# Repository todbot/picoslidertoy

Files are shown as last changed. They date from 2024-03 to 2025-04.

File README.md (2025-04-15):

# picoslidertoy
  
<a href="https://www.tindie.com/products/todbot/picoslidertoy-capsense-controller-for-pico/">
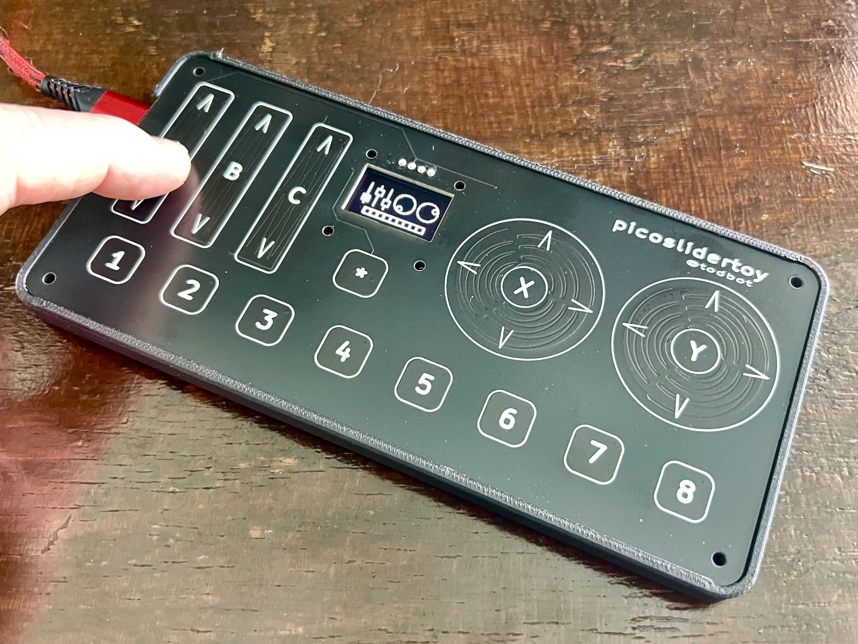
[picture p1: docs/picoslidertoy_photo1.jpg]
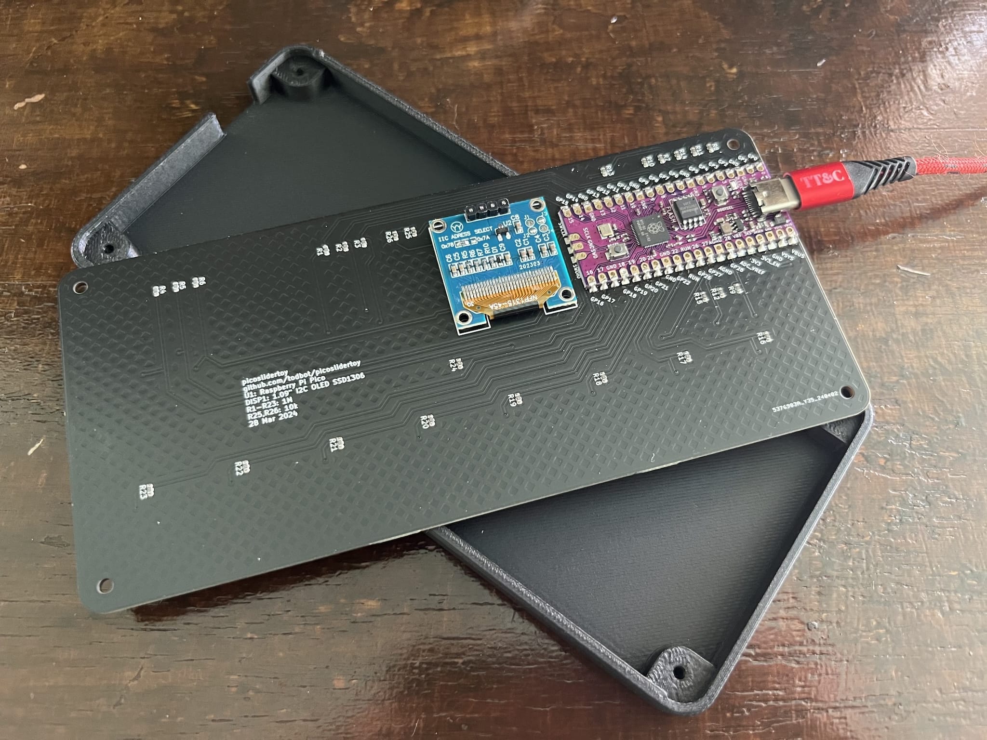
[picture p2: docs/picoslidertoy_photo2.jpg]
</a>


## Table of contents 

- [picoslidertoy](#picoslidertoy)
  - [Table of contents](#table-of-contents)
  - [What is it?](#what-is-it)
  - [Variants](#variants)
  - [Parts needed](#parts-needed)
  - [Soldering components](#soldering-components)
  - [Firmware installation / Installing apps](#firmware-installation--installing-apps)
    - [CircuitPython apps](#circuitpython-apps)
    - [Ready-to-go UF2 file](#ready-to-go-uf2-file)
    - [Installing by hand](#installing-by-hand)
  - [Why?](#why)
    - [What makes it special?](#what-makes-it-special)
    - [Press links](#press-links)

## What is it?
[picoslidertoy](https://github.com/todbot/picoslidertoy) is a touch-sensitive 
control surface that uses 24 GPIO pins of the Raspberry Pi Pico to provide:

- three linear sliders
- two rotary sliders
- nine buttons
- all capacitive touch 

It also includes a cutout for a reverse-mounted SSD1306 I2C OLED display. The Raspberry Pi Pico SMD mounts to the back of the board to provide a clean look for the touch surface.  The entire PCB is 165 mm x 76 mm (6.5" x 3.0").

The picoslidertoy can be a USB MIDI control surface, a USB Macropad keyboard with "analog" controls, or even a USB gamepad.  It can be programmed in [CircuitPython](https://circuitpython.org/) and [`touchio`](https://docs.circuitpython.org/en/latest/shared-bindings/touchio/index.html) or Arduino with my [`TouchyTouch library`](https://github.com/todbot/TouchyTouch).  Several example firmware apps are provided.

## Variants

There are two versions of the picoslidertoy available:

- black PCB -- production version with proper alignment of the cutout for standard 0.96" I2C OLED, comes with all SMD resistors soldered down  Note: the silkscreen on the back has a typo, saying `0.91" I2C OLED`. 

- green PCB -- prototype version with no components soldered down and where the I2C OLED display cutout is a little off. Still usable, or mount the display on the face. 

There is also a nice minimal 3d-printable enclosure available in the github repo (and visible in the photos above).  You really want a case for capacitive touch projects like this to reduce spurious readings. 

## Parts needed

In addition to the [picoslidertoy PCB](https://www.tindie.com/products/todbot/picoslidertoy-capsense-controller-for-pico/), you will need:

- Raspberry Pi Pico 
  - Must be w/ castellated pads & w/o headers,  ([like this](https://amzn.to/4d0KFZC))
  - For USB-C, consider this [USB-C 16 MB Pico clone](https://www.aliexpress.us/item/3256804731684211.html)
  - **(NOTE: NOT the Pico2, since its RP2350 chip has a hardware error)**

- I2C OLED display SSD1306 
   - 0.96" 128 x 64 pixels, in white
   - Pins must be in GND,VCC,SCL,SDA order 
   - Prefer the 27.5 mm wide displays over the 25 mm wide ones ([one example](https://amzn.to/3KDmy73))

- (If you have a green proto one, you will also need 24 x 1M 0603 resistors and 2 x 10k 0603 resistors)

- [3d printed case](./enclosure/picoslidertoy_case.stl) or M2.5 standoffs/screws or some other feet

## Soldering components

- **Pico**  -- the Pico is soldered down surface-mount style, using its castellated pads. 
  [This video soldering a Pico on picotouch](https://github.com/todbot/picotouch?tab=readme-ov-file#how-to-solder-the-pico) is how I do it for this board too.  It's technically surface-mount soldering, 
  but the pads are bigger than most through-hole pads and easy to solder to. 
  Note that Pico clones that don't have castellated pads like the real Pico will
  not work. 
  ([Youtube video with Pico SMD soldering tips](https://www.youtube.com/watch?v=dW9LiOq3Dso "Pico SMD soldering"))
  [](https://www.youtube.com/watch?v=dW9LiOq3Dso "Pico SMD soldering")
  
- **OLED Display** -- the display can either be mounted on the front (especially easy if your display's pins
  come pre-soldered) or from the back (my preference).  If mounting from the back, you first need to 
  desolder the 4-pin header on the display and mount a new 4-pin header "reverse" so that pins stick up
  from the front of the display. The main header body is still on the back of the display. 
  (The video below hopefully makes this clearer).  When soldering, do one pin first and check alignment,
  then solder the rest of the pins. Finish up by trimming the excess header pins. 
  ([Youtube video with picoslidertoy soldering tips](https://www.youtube.com/watch?v=zxt3xpre2Vg))
  [](https://www.youtube.com/watch?v=zxt3xpre2Vg "picoslidertoy soldering tips")

## Firmware installation / Installing apps

### CircuitPython apps

These are the apps currently available 
- [hwtest](https://github.com/todbot/picoslidertoy/blob/main/circuitpython/hwtest/code.py)
    -- a simple on/off test of the touch sensors, no display needed. Use serial REPL to see results

- [hwtest display](https://github.com/todbot/picoslidertoy/blob/main/circuitpython/hwtest_display/code.py) -- like `hwtest` but also outputs simple feedback via the display
 
- [midi_sliders](https://github.com/todbot/picoslidertoy/blob/main/circuitpython/midi_sliders/) -- MIDI controller where the sliders emit CCs and the buttons send NoteOn/NoteOffs

If you've never used a Pico or CircuitPython, there are several ways to put code on it. 
The two main ways I'll present here are:

- Ready-to-go UF2 file in "Releases" 
- Installing by hand:  CircuitPython, code.py, libraries 

### Ready-to-go UF2 file

Steps to install a UF2 file:

- Download a ready-to-go UF2 file from the [Releases section](https://github.com/todbot/picoslidertoy/releases) section
- Hold the BOOTSEL button on the picoslidertoy's Pico while plugging it into your computer
- Copy the UF2 file to the "RPI-RP2" Pico bootloader drive 
- Wait for a bit, then app is running!

In general, I'll try to make UF2 files available in the [Releases section](https://github.com/todbot/picoslidertoy/releases) for the different apps.

### Installing by hand 

Steps to install by hand: 

- Download this repo, either with a `git clone` or clicking on "Code / Download ZIP"
- Download the latest CircuitPython UF2 for Pico at https://circuitpython.org/board/raspberry_pi_pico/
- Install the CircuitPython UF2 (like in the above UF2 steps)
- Wait for CircuitPython to come up and present a CIRCUITPY drive
- Copy the files of the picoslidertoy app in question to CIRCUITPY:

  e.g. for `midi_sliders`, copy `code.py`, `slider_display.py`, `touchslider.py` to CIRCUITPY
  ```
  cp circuitpython/midi_sliders/* /Volumes/CIRCUITPY  # (if macos)
  ```
   
- Install CircuitPython libraries onto Pico

    If you have Python on your computer you can do:
    ```
    pip3 install circup
    circup install adafruit_midi adafruit_displayio_ssd1306 adafruit_hid
    ```
    Otherwise, download the [CircuitPython Libraries Bundle](https://circuitpython.org/libraries)
    and copy over the `adafruit_midi`, `adafruit_displayio_ssd1306` and `adafruit_hid` libraries to
    the `CIRCUITPY/lib` folder on the Pico.

## Why?

I wanted a way to experiment with linear and rotary touch sliders.  I made some [touchwheels](https://github.com/todbot/touchwheels) to give away for Hackaday Supercon 2023 and they were popular. I wanted a larger playground for experimenting with these controls. 

### What makes it special?

The 24 capacitive touch sensors are read directly by the Pico, either via CircuitPython's `touchio` library or the `TouchyTouch` Arduino library.  No external touch chip needed.  I think that's really cool!  Getting an "analog" value out of the three touch sensors that make up a linear or rotary touch slider is fairly simple but there are some tricks I'm developing to make the values stable.

picoslidertoy is also completely open source with schematic files in KiCad and software in CircuitPython and Arduino.

### Press links

- [Adafruit Show-N-Tell Live show 10 Apr 2024](https://www.youtube.com/live/9aliKuS8NTw?si=FC51cfeyoLF2YsNm&t=1055)
- [Hackster.io 11 Apr 2024 article](https://www.hackster.io/news/tod-kurt-s-picoslidertoy-delivers-25-capacitive-touch-inputs-to-a-raspberry-pi-pico-with-sliders-368dca30f01c)

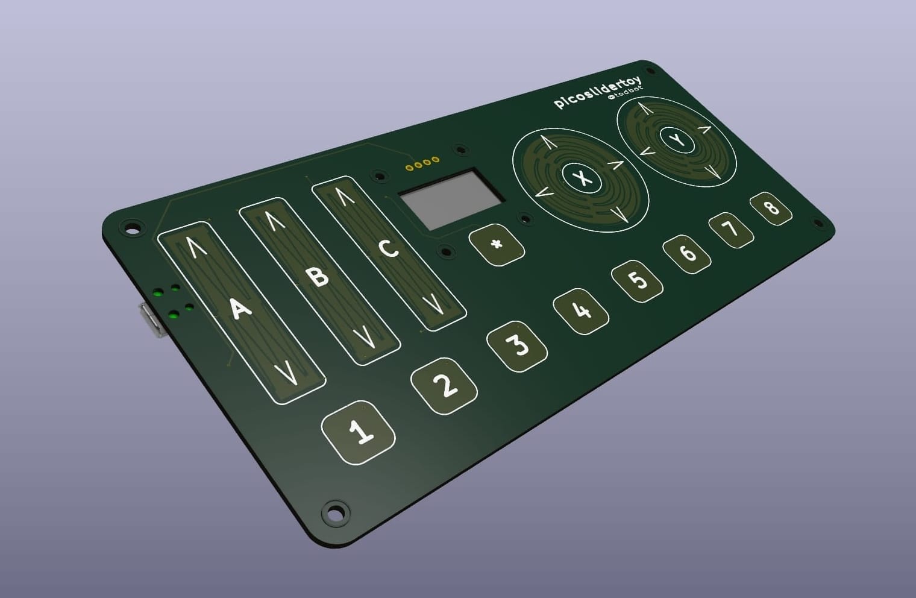
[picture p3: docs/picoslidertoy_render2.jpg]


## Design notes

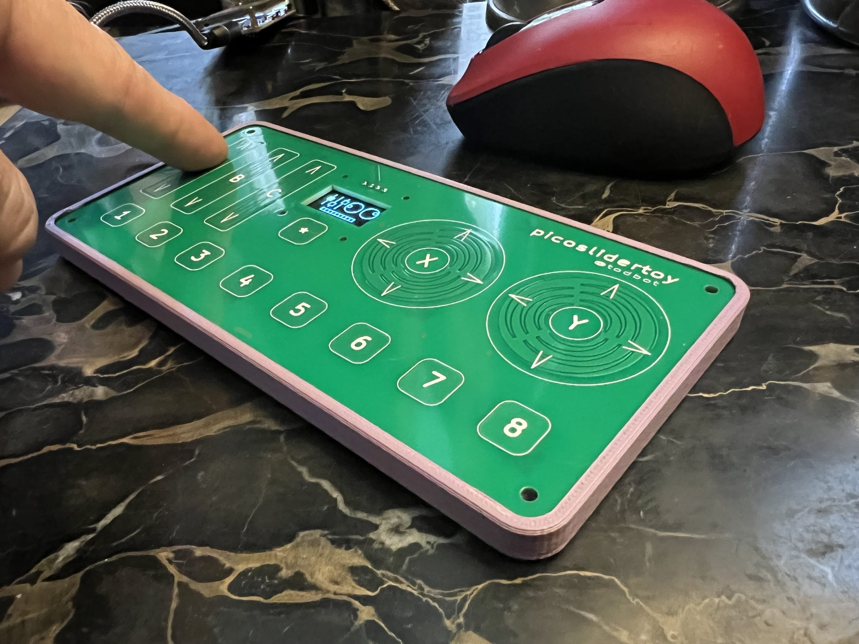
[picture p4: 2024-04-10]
docs/picoslidertoy-proto1-photo1.jpg

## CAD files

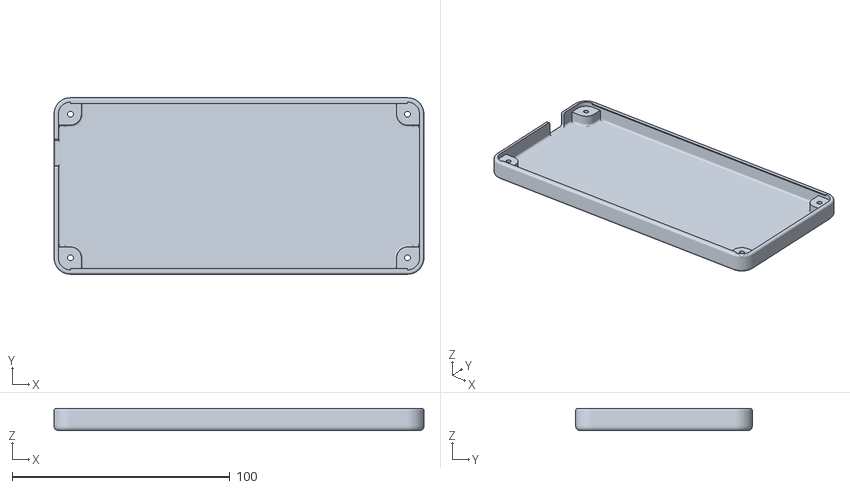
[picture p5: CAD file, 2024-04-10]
enclosure/picoslidertoy_case.stl
170.1 x 81.2 x 10.2

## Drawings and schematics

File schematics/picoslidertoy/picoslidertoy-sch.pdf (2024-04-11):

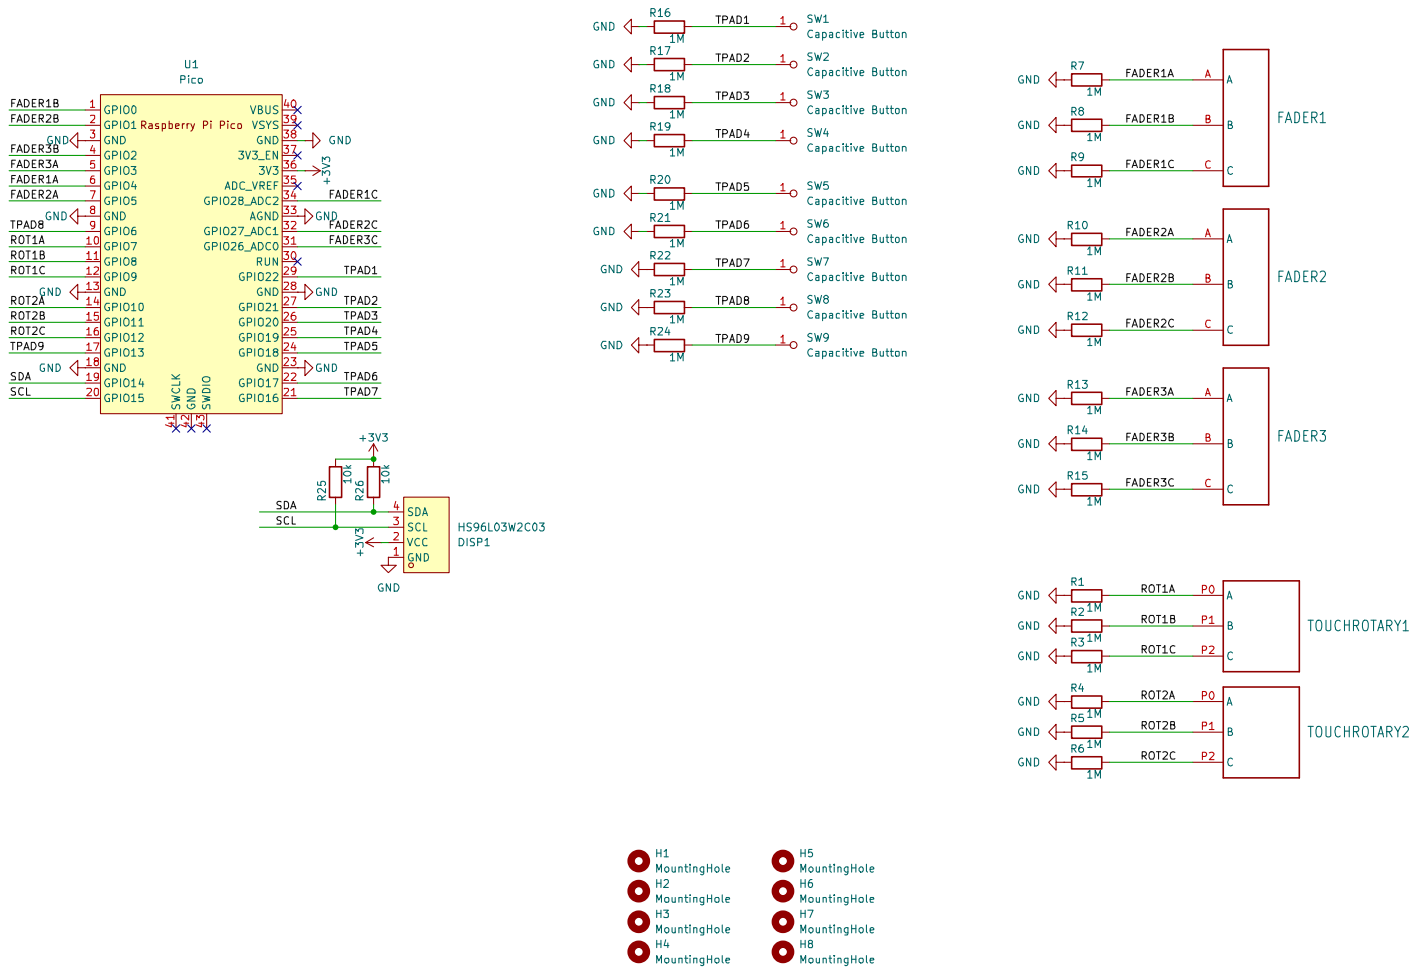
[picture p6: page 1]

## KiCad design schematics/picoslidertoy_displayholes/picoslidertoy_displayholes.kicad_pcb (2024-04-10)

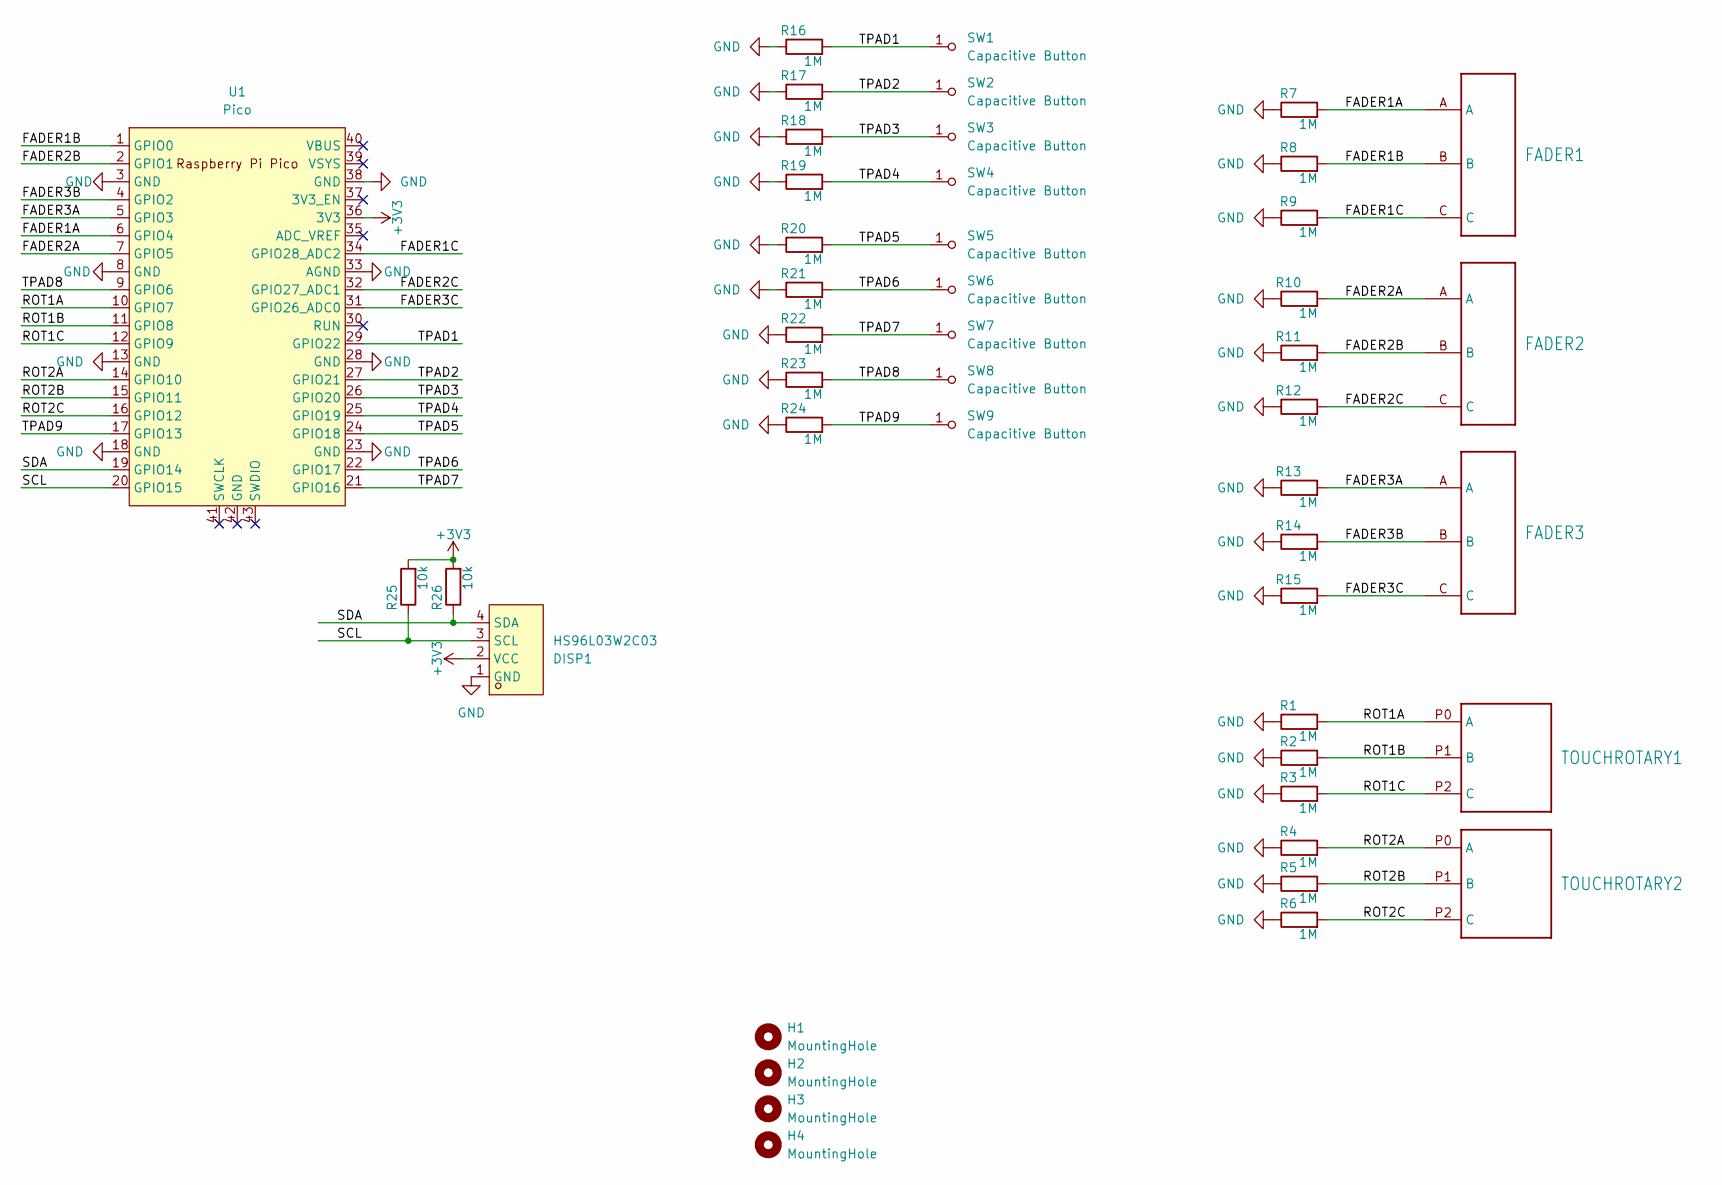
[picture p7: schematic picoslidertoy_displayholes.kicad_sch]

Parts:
DISP1: HS96L03W2C03; OLED-TH_under_fixed_L27.8-W27.2-P2.54_C9900033791; LCSC Part C5248080
FADER1, FADER2, FADER3: TOUCHSLIDER3_8x40B
H1, H2: MountingHole; MountingHole_2.7mm_M2.5_ISO14580
H3, H4: MountingHole; MountingHole_2.7mm_M2.5
R1, R2, R3, R4, R5, R6, R7, R8, R9, R10, R11, R12, R13, R14, R15, R16, R17, R18, R19, R20, R21, R22, R23, R24: 1M; R_0603_1608Metric
R25, R26: 10k; R_0603_1608Metric
SW1, SW2, SW3, SW4, SW5, SW6, SW7, SW8, SW9: Capacitive Button; Pad-CapacitiveTouch
TOUCHROTARY1, TOUCHROTARY2: TOUCHROTARY1B
U1: Pico; RPi_Pico_SMD

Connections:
+3V3: DISP1.2 (VCC), R25.2, R26.2, U1.36 (3V3)
/FADER1A: FADER1.A, R7.2, U1.6 (GPIO4)
/FADER1B: FADER1.B, R8.2, U1.1 (GPIO0)
/FADER1C: FADER1.C, R9.2, U1.34 (GPIO28_ADC2)
/FADER2A: FADER2.A, R10.2, U1.7 (GPIO5)
/FADER2B: FADER2.B, R11.2, U1.2 (GPIO1)
/FADER2C: FADER2.C, R12.2, U1.32 (GPIO27_ADC1)
/FADER3A: FADER3.A, R13.2, U1.5 (GPIO3)
/FADER3B: FADER3.B, R14.2, U1.4 (GPIO2)
/FADER3C: FADER3.C, R15.2, U1.31 (GPIO26_ADC0)
/ROT1A: R1.2, TOUCHROTARY1.P0 (A), U1.10 (GPIO7)
/ROT1B: R2.2, TOUCHROTARY1.P1 (B), U1.11 (GPIO8)
/ROT1C: R3.2, TOUCHROTARY1.P2 (C), U1.12 (GPIO9)
/ROT2A: R4.2, TOUCHROTARY2.P0 (A), U1.14 (GPIO10)
/ROT2B: R5.2, TOUCHROTARY2.P1 (B), U1.15 (GPIO11)
/ROT2C: R6.2, TOUCHROTARY2.P2 (C), U1.16 (GPIO12)
/SCL: DISP1.3 (SCL), R25.1, U1.20 (GPIO15)
/SDA: DISP1.4 (SDA), R26.1, U1.19 (GPIO14)
/TPAD1: R16.2, SW1.1 (A), U1.29 (GPIO22)
/TPAD2: R17.2, SW2.1 (A), U1.27 (GPIO21)
/TPAD3: R18.2, SW3.1 (A), U1.26 (GPIO20)
/TPAD4: R19.2, SW4.1 (A), U1.25 (GPIO19)
/TPAD5: R20.2, SW5.1 (A), U1.24 (GPIO18)
/TPAD6: R21.2, SW6.1 (A), U1.22 (GPIO17)
/TPAD7: R22.2, SW7.1 (A), U1.21 (GPIO16)
/TPAD8: R23.2, SW8.1 (A), U1.9 (GPIO6)
/TPAD9: R24.2, SW9.1 (A), U1.17 (GPIO13)
GND: DISP1.1 (GND), R1.1, R2.1, R3.1, R4.1, R5.1, R6.1, R7.1, R8.1, R9.1, R10.1, R11.1, R12.1, R13.1, R14.1, R15.1, R16.1, R17.1, R18.1, R19.1, R20.1, R21.1, R22.1, R23.1, R24.1, U1.3 (GND), U1.8 (GND), U1.13 (GND), U1.18 (GND), U1.23 (GND), U1.28 (GND), U1.33 (AGND), U1.38 (GND)

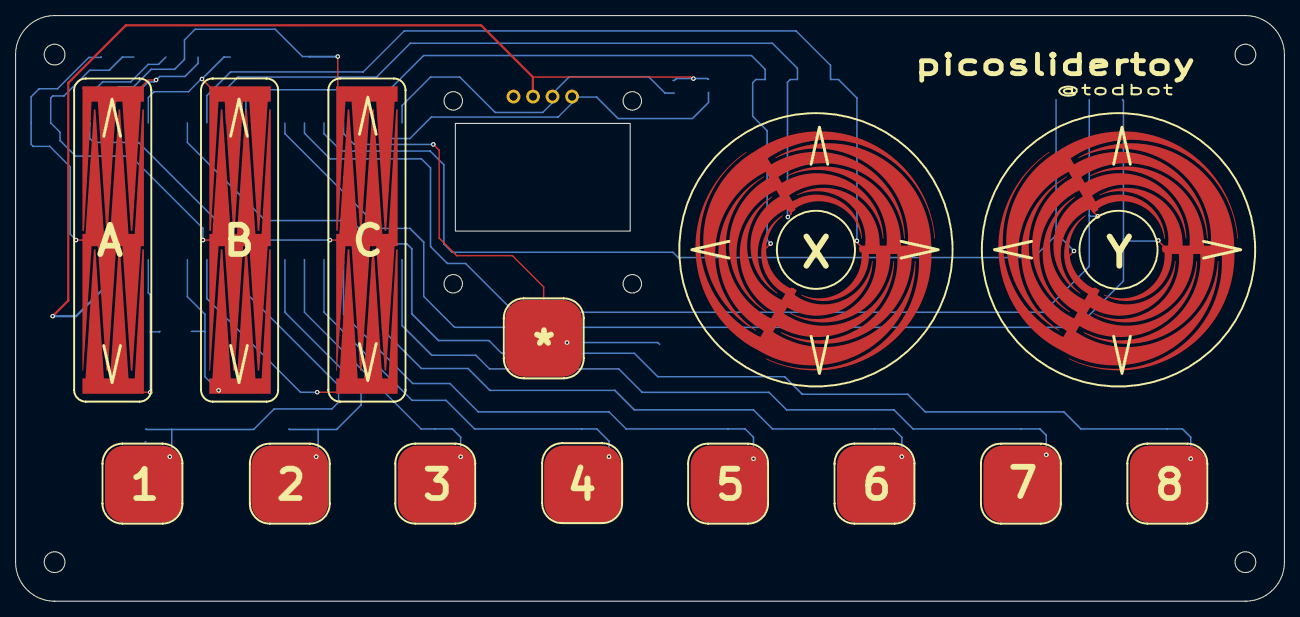
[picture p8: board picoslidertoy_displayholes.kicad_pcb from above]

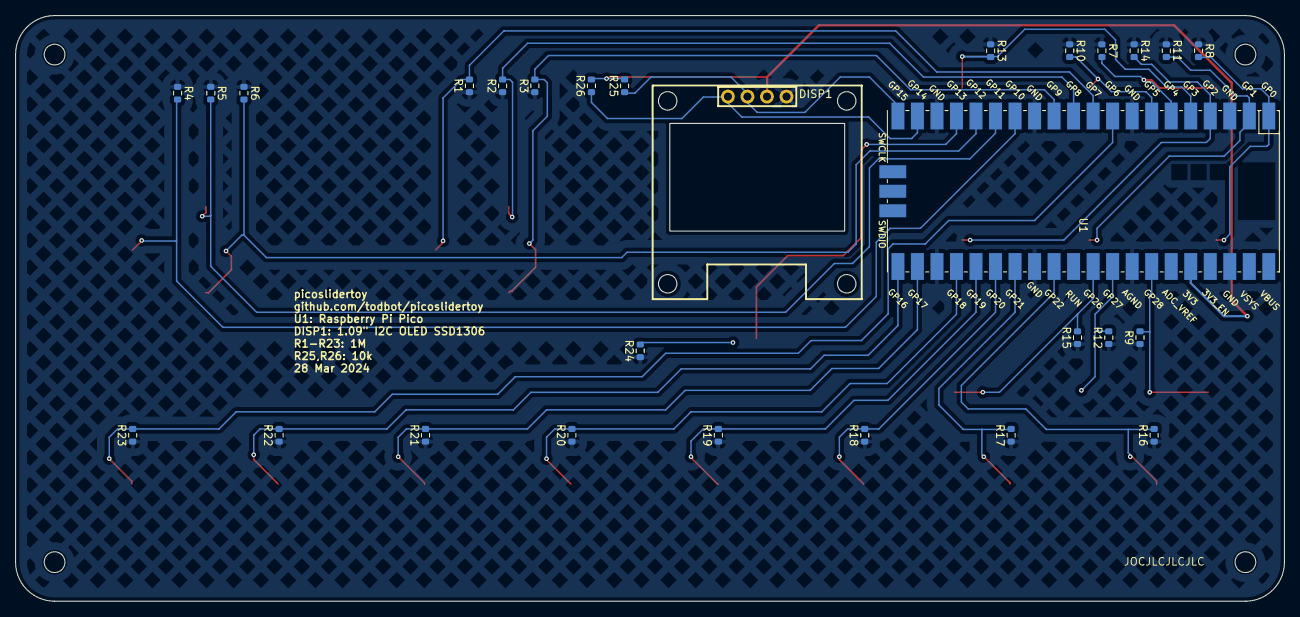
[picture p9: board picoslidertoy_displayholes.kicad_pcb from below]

Board: 2 copper layers, 165.1 x 76.2 mm, 46 parts (27 on the bottom side), 28 nets.

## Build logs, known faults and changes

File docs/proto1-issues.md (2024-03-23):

# PCB issues

* OLED display 
  * screw holes not in same spot as new displays from Amz
  * display is cutoff on top (shift up cutout by 0.5mm?)
  * display "*" button should be moved down ~6mm
  * how to solder this on reliably? 
  
* Fader sliders are too poopy?
*

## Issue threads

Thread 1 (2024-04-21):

Tindie link down

pierce-jason, 2024-04-21:
Your Tindie link is down (in repo description). 404.
Also, there's an article on hackster.io about your project with similarly broken Tindie link.

todbot, 2024-04-21:
Hi! Could you give the exact link you're having problems with?  The link in the README is:
 https://www.tindie.com/products/todbot/picoslidertoy-capsense-controller-for-pico/
and that currently works for me.

Closed 2024-06-05.

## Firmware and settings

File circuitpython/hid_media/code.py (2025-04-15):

#
# code.py -- turn picoslidertoy into HID controller
# 2025 - @relic-se / Cooper Dalrymple - github.com/relic-se/picoslidertoy
# 2024 - @todbot / Tod Kurt - github.com/todbot/picoslidertoy
#
# based off of "picotouch_test.py":
# picotouch_test.py -- Testing for tiny capsense controller using Pico,
# 2021 - @todbot / Tod Kurt - github.com/todbot/picotouch
#
# To use:
#
# 1. Install needed libraries:
#   circup install adafruit_displayio_ssd1306 adafruit_hid adafruit_display_emoji_text
# 2. Copy over files in this directory to CIRCUITPY:
#   cp circuitpython/hid_media/* /Volumes/CIRCUITPY/
#

import board
import touchio
import busio
import displayio
import i2cdisplaybus
import adafruit_displayio_ssd1306

import usb_hid
from adafruit_hid.keyboard import Keyboard
from adafruit_hid.keycode import Keycode
from adafruit_hid.consumer_control import ConsumerControl
from adafruit_hid.consumer_control_code import ConsumerControlCode

from touchslider import TouchWheel, TouchSlider
from slider_display import FaderDisplay, WheelDisplay, PadsDisplay

# slider config
MAX_REPEATS = 1  # maximum number of repeats when using sliders

# pin definitions
faderA_pins = (board.GP4, board.GP0, board.GP28)
faderB_pins = (board.GP5, board.GP1, board.GP27)
faderC_pins = (board.GP3, board.GP2, board.GP26)
wheelX_pins = (board.GP7, board.GP8, board.GP9)
wheelY_pins = (board.GP10, board.GP11, board.GP12)
pad_pins = (board.GP22, board.GP21, board.GP20, board.GP19,
            board.GP18, board.GP17, board.GP16, board.GP6, board.GP13)
i2c_sda_pin, i2c_scl_pin = board.GP15, board.GP14

# set up the touch controls
sliders = (
    TouchSlider(faderA_pins),
    TouchSlider(faderB_pins),
    TouchSlider(faderC_pins),
    TouchWheel(wheelX_pins, offset=0.25),
    TouchWheel(wheelY_pins, offset=0.25),
)
pads = [touchio.TouchIn(pin) for pin in pad_pins]

# virtual on-screen displays of controls
slider_displays = (
    FaderDisplay(10 + 15*0, 10, 8, 35),
    FaderDisplay(10 + 15*1, 10, 8, 35),
    FaderDisplay(10 + 15*2, 10, 8, 35),
    WheelDisplay(70 + 0*35, 25, 15, knob_w=9, phase_offset=-0.25),
    WheelDisplay(70 + 1*35, 25, 15, knob_w=9, phase_offset=-0.25),
)
pad_displays = PadsDisplay(16, 50, n=9, pad_h=11, pad_w=11)

# set up usb hid
keyboard = Keyboard(usb_hid.devices)
cc = ConsumerControl(usb_hid.devices)

# map hid actions
# the "*" button is reserved for mode switching
hid_actions = {
    "button": (  # (device, icon, action,),
        (keyboard, "",   (Keycode.CONTROL, Keycode.F1,)),             # 1
        (keyboard, "",   (Keycode.CONTROL, Keycode.F2,)),             # 2
        (keyboard, "",   (Keycode.CONTROL, Keycode.F3,)),             # 3
        (keyboard, "",   (Keycode.CONTROL, Keycode.F4,)),             # 4
        (cc,       "⏏️", (ConsumerControlCode.EJECT,)),               # 5
        (cc,       "🔇", (ConsumerControlCode.MUTE,)),                # 6
        (cc,       "⏮️", (ConsumerControlCode.SCAN_PREVIOUS_TRACK,)), # 7
        (cc,       "⏭️", (ConsumerControlCode.SCAN_NEXT_TRACK,)),     # 8
        (cc,       "⏯️", (ConsumerControlCode.PLAY_PAUSE,)),          # *
    ),
    "slider": (  # (device, sensitivity, icon, decrement, increment),
        (keyboard, 16, "",   (Keycode.CONTROL, Keycode.F9,),              (Keycode.CONTROL, Keycode.F10,)),             # A
        (keyboard, 16, "",   (Keycode.CONTROL, Keycode.F11,),             (Keycode.CONTROL, Keycode.F12,)),             # B
        (cc,       16, "🔆", (ConsumerControlCode.BRIGHTNESS_DECREMENT,), (ConsumerControlCode.BRIGHTNESS_INCREMENT,)), # C
        (cc,       8,  "⏩", (ConsumerControlCode.REWIND,),               (ConsumerControlCode.FAST_FORWARD,)),         # X
        (cc,       16, "🔊", (ConsumerControlCode.VOLUME_DECREMENT,),     (ConsumerControlCode.VOLUME_INCREMENT,)),     # Y
    ),
}

def do_hid_action(group:str, index:int, option:int = 0, repeats:int = 1) -> bool:
    if not group in hid_actions or index >= len(hid_actions[group]):
        return False
    
    action = hid_actions[group][index]
    if len(action) < 3 + option:
        return False
    
    device = action[0]
    if not type(device) in (Keyboard, ConsumerControl):
        return False
    
    action = hid_actions[group][index]
    if not type(action) is tuple:
        return False

    if len(action) < (4 if group is "slider" else 3) + option:
        return False
    command = action[(3 if group is "slider" else 2) + option]

    if not type(command) is tuple or not type(command[0]) is int:
        return False
    
    repeats = int(min(max(repeats, 1), MAX_REPEATS))
    for i in range(repeats):
        device.send(*command)
    return True

# set up the display
dw,dh = 128, 64
displayio.release_displays()
i2c = busio.I2C(scl=i2c_sda_pin, sda=i2c_scl_pin, frequency=1_000_000)
display_bus = i2cdisplaybus.I2CDisplayBus(i2c, device_address=0x3c)
display = adafruit_displayio_ssd1306.SSD1306(display_bus, width=dw, height=dh)
maingroup = displayio.Group()
display.root_group = maingroup

for s in slider_displays:
    maingroup.append(s)
maingroup.append(pad_displays)

# button icons
for i in range(len(pads)):
    if i >= len(hid_actions["button"]):
        break
    pad_displays.icon(i, hid_actions["button"][i][1])

# slider icons
for i, slider in enumerate(slider_displays):
    if i >= len(hid_actions["slider"]):
        break
    slider.icon(hid_actions["slider"][i][2])

# used to keep track of which note pads are curerntly pressed
pad_state = [False] * len(pads)
slider_state = [None] * len(sliders)

while True:
    for i, slider in enumerate(sliders):
        pos = slider.pos()
        if pos is not None:   # touched!
            slider_displays[i].pos(pos)   # fixme: need ".pos(pos-0.5)" for fader
            slider_displays[i].touch(True)

            segments = hid_actions["slider"][i][1]
            val = int((1-pos) * segments)
            chng = 0
            if slider_state[i] is not None and val != slider_state[i]:
                chng = val - slider_state[i]
                # BUG: jumps when crossing from 0.99 to 0.01
                do_hid_action("slider", i, int(chng > 0), abs(chng))
            slider_state[i] = val

            print("slider:%d: %1.2f val:%d chng:%d" % (i,pos,val,chng))
        else:
            slider_displays[i].touch(False)
            slider_state[i] = None
            
    for i, pad in enumerate(pads):
        v = pad.value
        if i < 8:
            pad_displays.set(i, v)
        if pad_state[i] != v:
            if v:
                do_hid_action("button", i)
            pad_state[i] = v
            print("pad:%d: v:%d" % (i,v))

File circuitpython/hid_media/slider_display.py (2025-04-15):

## pylint: disable=invalid-name
# SPDX-FileCopyrightText: Copyright (c) 2024 Tod Kurt
# SPDX-License-Identifier: MIT
"""
`slider_display`
================================================================================

Create virtual displays for linear TouchSliders and rotary TouchWheels

Part of picoslidertoy
2024 - @todbot / Tod Kurt - github.com/todbot/picoslidertoy

Originally part of the 'touchwheels' project: https://github.com/todbot/touchwheels/
2023 - @todbot / Tod Kurt

"""

import math
import displayio
import vectorio
from adafruit_display_emoji_text import EmojiLabel

class FaderDisplay(displayio.Group):
    """Display a simple virtual fader with virtual 'knob' indicating position """
    def __init__(self, x,y, w,h, knob_w=11):
        super().__init__(x=x,y=y,scale=1)
        self.w, self.h, self.knob_w = w,h, knob_w
        pW = displayio.Palette(1)
        pB = displayio.Palette(1)
        pW[0], pB[0] = 0xffffff, 0x000000
        self.append(vectorio.Rectangle(pixel_shader=pW, width=1, height=h, x=w//2, y=0))
        self.knob = displayio.Group()
        knob_handle = vectorio.Rectangle(pixel_shader=pW, width=knob_w, height=knob_w, x=0, y=0)
        knob_touch =  vectorio.Rectangle(pixel_shader=pB, width=knob_w-2, height=knob_w-2, x=1, y=1)
        self.knob.append(knob_handle)
        self.knob.append(knob_touch)
        self.knob.y = h//2
        self.append(self.knob)
        self.knob_icon = None

    def pos(self,v):
        """Set position of virtual fader"""
        self.knob.y = int(v * (self.h-self.knob_w/2))
    def touch(self,v):
        """Set to indicate if fader is being curerently touched"""
        self.knob[1].hidden = v

    def icon(self,v):
        if self.knob_icon:
            self.knob.remove(self.knob_icon)
            del self.knob_icon
        if not v:
            self.knob_icon = None
        else:
            self.knob_icon = EmojiLabel(v, scale=1)
            self.knob_icon.anchor_point = (0.5, 0.5)
            self.knob_icon.anchored_position = (self.knob_w/2, 2)
            self.knob.append(self.knob_icon)

class WheelDisplay(displayio.Group):
    """Simple round display with 'knob' indicating wheel position"""
    def __init__(self, x,y, r, knob_w=8, phase_offset=0):
        super().__init__(x=x,y=y,scale=1)
        self.r = r
        self.phase_offset = phase_offset
        self.knob_w = knob_w
        pW = displayio.Palette(1)
        pB = displayio.Palette(1)
        pW[0], pB[0] = 0xffffff, 0x000000
        # the outer circle, with black covering up most to make a line
        self.append(vectorio.Circle(pixel_shader=pW, radius=r, x=0, y=0))
        self.append(vectorio.Circle(pixel_shader=pB, radius=r-1, x=0, y=0))
        self.knob = displayio.Group()
        knob_handle = vectorio.Circle(pixel_shader=pW, radius=knob_w//2, x=0, y=0)
        knob_touch = vectorio.Circle(pixel_shader=pB, radius=knob_w//2-1, x=0, y=0)
        self.knob.append(knob_handle)
        self.knob.append(knob_touch)
        self.append(self.knob)
        self.icon_label = None
        self.pos(0)
        
    def pos(self,v):
        v += 0.25 + self.phase_offset  # drawing is offset by 1/4 turn
        self.knob.x = int((self.r-self.knob_w/2) * math.sin(v*6.28))
        self.knob.y = int((self.r-self.knob_w/2) * math.cos(v*6.28))
        
    def touch(self,v):
        self.knob[1].hidden = v

    def icon(self,v):
        if self.icon_label:
            self.remove(self.icon_label)
            del self.icon_label
        if not v:
            self.icon_label = None
        else:
            self.icon_label = EmojiLabel(v, scale=1)
            self.icon_label.anchor_point = (0.5, 0.5)
            self.icon_label.anchored_position = (0, -2)
            self.append(self.icon_label)

class PadsDisplay(displayio.Group):
    """Simple list of on/off boxes representing touch pads"""
    def __init__(self, x,y, n, pad_h=8, pad_w=8):
        super().__init__(x=x,y=y,scale=1)
        self.n = n
        self.pad_h, self.pad_w = pad_h, pad_w
        pW = displayio.Palette(1)
        pB = displayio.Palette(1)
        pW[0], pB[0] = 0xffffff, 0x000000
        self.append(vectorio.Rectangle(pixel_shader=pW, width=(pad_w)*n+2, height=pad_h, x=0, y=0))
        for i in range(n):
            self.append(vectorio.Rectangle(pixel_shader=pB, width=pad_w-2, height=pad_h-2, x=2+i*pad_w, y=1))
        self.icons = [None for i in range(n)]

    def set(self,i,v):
        self[i+1].hidden = v

    def icon(self,i,v):
        if self.icons[i]:
            self.remove(self.icons[i])
            # BUG: `del self.icons[i]`?
        if not v:
            self.icons[i] = None
        else:
            label = EmojiLabel(v, scale=1)
            label.anchor_point = (0.5, 0.5)
            label.anchored_position = (self.pad_w*(i+0.5), self.pad_h//2)
            self.append(label)
            self.icons[i] = label

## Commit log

2024-03-16 hardware reimplemented in kicad from eagle version, zero unrouted but drc errors
    [picoslidertoy.kicad_pcb, picoslidertoy.kicad_sch]
2024-03-16 pcb fixes
    [picoslidertoy.kicad_pcb, picoslidertoy.kicad_sch]
2024-03-16 pcb silksreen
    [picoslidertoy.kicad_pcb, picoslidertoy.kicad_sch]
2024-03-17 pcb proto submitted to fab
    [picoslidertoy.kicad_pcb]
2024-03-23 circuitpython hwtest
2024-03-23 circuitpython slider_test as in picoslider prototype demo video, save proto1 pcb as own kicad project
    [picoslidertoy_proto1.kicad_pcb, picoslidertoy_proto1.kicad_sch]
2024-03-24 fix display knob bounds
    [code.py]
2024-03-25 circuitpython midi_sliders demo
2024-03-29 pcb display positioning tune
    [picoslidertoy.kicad_pcb, picoslidertoy.kicad_sch]
2024-03-30 pcb display position tuning
    [picoslidertoy.kicad_pcb, picoslidertoy.kicad_sch]
2024-04-10 added enclosure stl, small reorg
    [picoslidertoy.kicad_pcb, picoslidertoy.kicad_sch, picoslidertoy_case.stl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]
2024-04-11 add scale to circuitpython midi_sliders
2024-04-15 readme: added some soldering tips
2024-04-16 update readme with apps info, new display hole-less version
    [picoslidertoy_displayholes.kicad_pcb, picoslidertoy_displayholes.kicad_sch]
2024-04-16 new display hole-less pcb to fab
    [picoslidertoy.kicad_pcb]
2024-04-16 add link to enclosure
